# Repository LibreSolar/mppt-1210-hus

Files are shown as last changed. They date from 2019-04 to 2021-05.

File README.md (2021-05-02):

# 10A MPPT Charge Controller with USB

 Evaluation phase

User manual: [HTML](https://libre.solar/mppt-1210-hus/) / [PDF](https://libre.solar/mppt-1210-hus/manual.pdf)

Schematic: [PDF file](build/mppt-1210-hus_schematic.pdf)

Bill of Materials: [CSV file](build/mppt-1210-hus_bom.csv) or [interactive HTML BOM](https://libre.solar/mppt-1210-hus/mppt-1210-hus_ibom.html)

Firmware repository: [LibreSolar/charge-controller-firmware](https://github.com/LibreSolar/charge-controller-firmware)

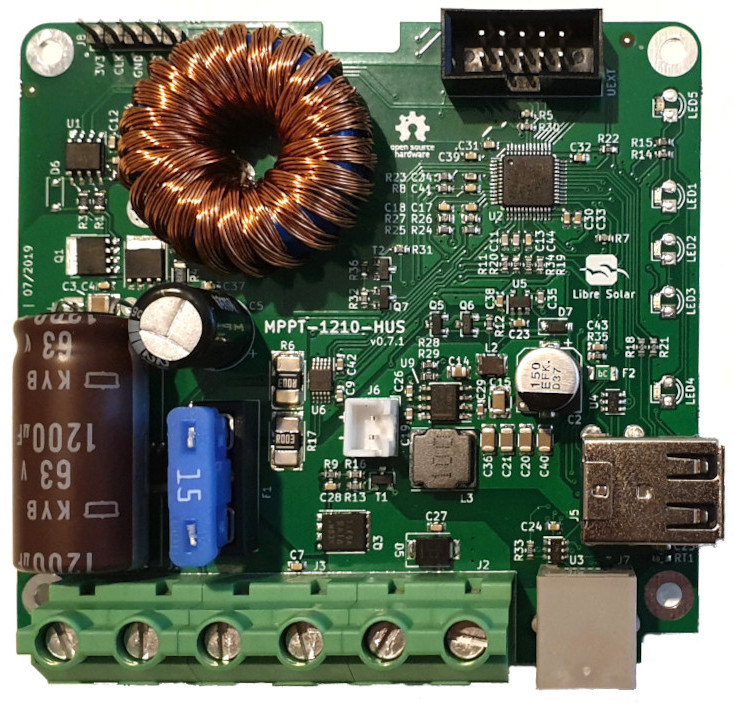
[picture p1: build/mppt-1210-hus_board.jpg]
Charge controller PCB


## Features:

- 12V battery voltage
- 40V max. solar input (36 to 48-cell panels, ideally so-called 12V panels with 36 cells)
- 10A max. charge current
- 10A max. load output current
- Low-power 32bit ARM MCU (STM32L072)
- Expandable via Olimex Universal Extension Connector (UEXT) featuring
   I2C, Serial and SPI interface (e.g. used for display, WIFI communication, etc.)
- USB charging
- High-side load switching

## Built-in protection:

- Overvoltage
- Undervoltage
- Overcurrent
- PV short circuit
- PV reverse polarity
- Battery reverse polarity (destructive, fuse is blown)

## Manual

The manual is auto-generated from the markdown files in the `manual` subfolder. See [here](https://github.com/LibreSolar/md-manual-template) for further information regarding the automated deployment.

You can contribute to the manual by cloning the repository to your private GitHub workspace and sending pull-requests with upates you made.

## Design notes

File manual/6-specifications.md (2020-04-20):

# Specifications

--------------------------------------------------------------------------------------------
Feature                         Value                   Comment
------------------------------  ----------------------- ------------------------------------
**Battery**

Nominal system voltage          12 V

Maximum voltage                 16 V

Maximum charge current          10 A

Quiescent current               < 10 mA

**PV module input**

Maximum open circuit voltage    40 V                    low temperature to be considered

Number of cells per module      36 to 48

Maximum short circuit current   10 A

Maximum nominal power           150 W

Conversion efficiency           >98% max.

**Load output**

Maximum current                 10 A

Switch type                     high-side

**USB charging port**

Maximum current                 2.0 A                   total for both ports

**Standard settings**

Battery type                    Lead-acid               safe general settings, also
                                                        suitable for LFP

Charge algorithm                3-stage                 configurable

Topping / absorption voltage    14.4 V                  configurable

Trickle charging                13.8 V                  configurable

Load disconnect voltage         11.7 V                  configurable, current-compensated

Load reconnect voltage          12.3 V                  configurable

Temperature compensation        -3 mV/K/cell            configurable

**Interfaces**

UEXT                            I2C, SPI, UART          internal, can be used for
                                                        displays, etc.

LS.one                                                  for external communication

**Protection**

Overvoltage

Undervoltage

Overcurrent

PV short circuit

PV reverse polarity                                     for max. module open circuit
                                                        voltage of around 40V

Battery reverse polarity                                destructive, fuse is blown

**Environmental conditions**

Operating ambient temperature   -10 °C to +50 °C

Storage temperature             -20 °C to +60 °C

Humidity                        <95%, non-condensing

**Mechanical design**

Screw terminals                 max. 6 mm² / AWG10

Type of internal fuse           15 A                    Automotive blade fuse (ATO)

Protection class                IP 20                   with housing (3D files available)

Weight

Dimensions

**Standards**

Power and function              EN/IEC 62509,           Tested in non-certified lab only
                                EN/IEC 62093
------------------------------  ----------------------- ------------------------------------

Table: Overview of specifications

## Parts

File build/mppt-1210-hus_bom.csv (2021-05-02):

Component | References | Value | Footprint | Description | Quantity Per PCB | Manufacturer | PartNumber | Remarks | Config | DNF | Supplier
1 | C35 | 100p | C_0603_1608 | Unpolarized capacitor | 1 | Yageo | CC0603JRNPO9BN101 | NP0/C0G
2 | C6 C11 C13 | 1n | C_0603_1608 | Unpolarized capacitor | 3 | Murata | GRM1885C2A102JA01D | NP0/C0G
3 | C4 C7 C8 C17 C18 C27 C28 C37 C41 C44 | 10n | C_0603_1608 | Unpolarized capacitor | 10 | Murata | GCM188R72A103KA37D | 100V, X7R 100V (not needed), X7R
4 | C9 C10 C19 C24 C25 C26 C30 C31 C32 C39 C42 C43 | 100n | C_0603_1608 | Unpolarized capacitor | 12 | Yageo | CC0603KRX7R9BB104
5 | C29 | 220n | C_0603_1608 | Unpolarized capacitor | 1 | Murata | GCM188R71E224KA55D | 25V, X7R
6 | C14 | 1u | C_0805_2012 | Unpolarized capacitor | 1 | Yageo | CC0805KKX7R9BB105
7 | C12 C23 C33 C34 C38 | 2.2u | C_0603_1608 | Unpolarized capacitor | 5 | Murata | GRM188R61E225KA12D | 25V, X5R
8 | C3 | 4.7u | C_1210_3225 | Unpolarized capacitor | 1 | Murata | GRJ32DC72A475KE11L | 100V, X7S
9 | C15 | 10u | C_1210_3225 | Unpolarized capacitor | 1 | Samsung | CL31A106KAHNNNE | 25V, X7R
10 | C20 C21 C36 C40 | 22u | C_1206_3216 | Unpolarized capacitor | 4 | Samsung | CL31B226MPHNNNE | 10V
11 | C2 | 150u | CP_Elec_8x6.2 | Polarised capacitor | 1 | Panasonic | EEEFK1E151P | 25V
12 | C5 | 820u | CP_Radial_D10.0mm_P5.00mm | Polarised capacitor | 1 | Panasonic | EEU-FR1E821 | 25V, 2.18A, 10x20 mm
13 | C1 | 1200u | CP_Radial_L31.5mm_D16.0mm_P7.50mm_horizontal | Polarised capacitor | 1 | United Chemi-Con | EKYB630ELL122MLN3S | 63V, 3.0A, 16x31.5
14 | D1 D4 D7 | 1N4148 | D_SOD-123 | Diode | 3 | Diodes Inc. | 1N4148W-7-F
15 | D5 | SMBJ24A | D_SMB | Diode zener | 1 | Bourns | SMBJ24A
16 | F1 | 25A | KEYSTONE-FUSE-3557-2 | Fuse | 1 | Keystone | 3557-2
17 | F2 | 50mA | R_1206_3216 |  | 1 | Bel | 0ZCJ0005FF2E
18 | J7 | 6P6C | RJ25_6P6C_TabUp | RJ connector, 6P6C (6 positions 6 connected), RJ12/RJ18/RJ25 | 1 | Wurth Electronics | 615006138421 | Alternative: Pulse E5566-Q0LK22-L
19 | J1 J2 J3 | MKDS_5-2_952 | Phoenix_Contact_MKDS_5-2-952 |  | 3 | Phoenix Contact | 1714971
20 | J6 | PWR_12V | JST_XH_B02B-XH-A_1x02_P2.50mm_Vertical | Generic connector, single row, 01x02, script generated (kicad-library-utils/schlib/autogen/connector/) | 1 | JST | B2B-XH-A (LF)(SN)
21 | J8 | ST_Nucleo_SWD | PinHeader_1x05_P2.54mm_Vertical |  | 1 | Harwin | M20-9990546 | Alternative: Standard 2.54 mm pitch header 1x5
22 | J4 | UEXT | Box_Header_2x05x2.54mm_Straight |  | 1 | On Shore Technology Inc. | 302-S101
23 | J5 | USB_A_stacked | USB_A_Wuerth_61400826021_Horizontal_Stacked | USB Type A connector (stacked) | 1 | CUI | UJ2-ADH-1-TH | Alternative: Wuerth 61400826021
24 | L2 | 2.2uH | L_1210_3225Metric | Inductor | 1 | Tayo Yuden | BRL3225T2R2M
25 | L3 | 10uH | Bourns_SRN8040TA | Inductor | 1 | Tayo Yuden | NR8040T100M | Alternative: Bourns SRN8040TA-100M
26 | L1 | 47uH | L-FERYSTER-DTMSS-27_47uH | Inductor | 1 | Feryster | DTMSS-27/0,047/15-HX |  |  |  | Feryster
27 | LED4 LED5 | green | LED_0603_D3.0mm |  | 2 | Lite-On | LTST-C190KGKT | Alternative: LTL-4231 (3mm THT)
28 | LED1 LED2 LED3 | yellow | LED_0603_D3.0mm |  | 3 | Lite-On | LTST-C191KSKT | Alternative: LTL-1CHY (3mm THT)
29 | Q3 | BSC084P03NS3 | 5X6_MOSFET | Transistor P-MOSFET (general) | 1 | Infineon | BSC084P03NS3GATMA1 | Alternative: SI7149ADP-T1-GE3
30 | Q5 Q6 Q7 | BSS83P | SOT-23 | P-MOSFET transistor, gate/source/drain | 3 | Infineon | BSS83P H6327
31 | Q1 Q2 Q4 | PSMN5R2-60YLX | 5X6_MOSFET | Transistor N-MOSFET (general) | 3 | Nexperia | PSMN5R2-60YLX | Alternative: BUK9Y6R0-60E
32 | R6 R17 | 3m | R_Bourns_CRE2512 | Resistor | 2 | Bourns | CRE2512-FZ-R003E-3
33 | R4 | 2.2 | R_1206_3216 | Resistor | 1 | Yageo | RC1206FR-072R2L
34 | R1 R3 R10 | 4.7 | R_0805_2012 | Resistor | 3 | Yageo | RC0805FR-074R7L
35 | R8 | 100 | R_0603_1608 | Resistor | 1 | Yageo | RC0603FR-07100RL
36 | R11 R14 R15 R18 R20 R21 | 470 | R_0603_1608 | Resistor | 6 | Yageo | RC0603FR-07470RL
37 | R5 R7 R13 R30 R33 R34 | 2.2k | R_0603_1608 | Resistor | 6 | Yageo | RC0603FR-072K2L
38 | R26 R27 | 5.6k | R_0603_1608 | Resistor | 2 | Yageo | RC0603FR-075K6L
39 | R9 R16 R19 R31 | 10k | R_0603_1608 | Resistor | 4 | Yageo | RC0603FR-0710KL
40 | R29 R32 | 24.9k | R_0603_1608 | Resistor | 2 | Yageo | RC0603FR-0724K9L
41 | R12 R22 R23 R24 R25 R28 R35 R36 | 100k | R_0603_1608 | Resistor | 8 | Yageo | RC0603FR-07100KL
42 | R2 | 1M | R_0603_1608 | Resistor | 1 | Yageo | RC0603FR-071ML
43 | RT1 | 10k NTC | R_0603_1608 | Thermistor with Negative Temperature Coefficient (NTC) | 1 | Murata | NCU18XH103E6SRB
44 | T1 T2 | MMBT3904 | SOT-23 | 0.8A Ic, 45V Vce, NPN Transistor, SOT-23 | 2 | Diodes Inc. | MMBT3904-7-F
45 | U5 | AP2210-3.3 | SOT-23-5 | 300mA low dropout linear regulator, shutdown pin, 1.5V fixed positive output, SOT-23-5 package | 1 | Diodes Inc. | AP2210K-3.3TRG1 | Alternative: MIC5225
46 | U3 U4 | D1213A-04SO | SOT-23-6 | Transient voltage suppressor designed to protect high speed data lines from ESD, EFT, and lightning | 2 | Diodes Inc. | D1213A-04SO | Alternative: IP4220CZ6
47 | U6 | INA2181 | VSSOP-10_3.0x3.0mm_P0.5mm |  | 1 | Texas Instruments | INA2181A2IDGS | Gain 50
48 | U1 | LM5109BMA | SOIC-8_3.9x4.9mm_Pitch1.27mm |  | 1 | Texas Instruments | LM5109BMAX/NOPB
49 | U9 | LMR33630 | TI_SO-PowerPAD-8_ThermalVias | SIMPLE SWITCHER® 3.8V to 36V, 3A Synchronous Buck Converter With Ultra-Low EMI | 1 | Texas Instruments | LMR33630ADDA | 400 kHz version
50 | U2 | STM32L072CZT6 | LQFP-48_7x7mm_P0.5mm | ARM Cortex-M0+ MCU, 192KB flash, 20KB RAM, 32MHz, 1.65-3.6V, 37 GPIO, LQFP-48 | 1 | ST Microelectronics | STM32L072CZT6 | Alternative: STM32L073CZT6

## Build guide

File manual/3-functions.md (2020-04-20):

# Description of Functions

The following chapter describes the primary functions of the charge controller. With expert knowledge, the firmware can be adjusted to suit your own needs and implement new features, including different control algorithms, wireless communication interfaces, displays, etc.

## MPPT

This charge controller is a so-called maximum power point tracker (MPPT), which automatically adapts its input voltage to the connected solar panel to extracts as much power as possible.

The MPPT function can only be achieved using a DC/DC converter, which is the core part of the charge controller PCB. It can be recognized by the large inductor and the large electrolytic input and output filter capacitors.

## Three-stage battery charging

The advanced 3-stage battery charging increases life of lead-acid batteries. The setpoints for the different stages are fully configurable via the serial interface and can be adjusted to your system setup.

- **Bulk stage**

  The battery is charged with maximum possible current until the topping stage voltage limit is reached. This is the stage where the MPPT algorithm is active.

- **Topping stage**

  The batteries are charged for some time using the maximum charge voltage. After a current cutoff limit or a time limit is reached, the charger goes into trickle mode for lead-acid batteries or into standby mode for Li-ion batteries.

  This stage is also called **absorption** mode. In case of Li-ion batteries, this is the constant voltage (CV) charging phase.

- **Trickle stage**

  This stage is kept forever for a lead-acid battery and keeps the battery at full state of charge. If too much power is drawn from the battery, the charger automatically goes back to bulk charging stage.

## Load output

In order to protect the battery from deep-discharge, consumers connected to the load ouput are automatically disconnected at low state of charge. As soon as the voltage rises again, the load port is switched back on.

## USB output

The USB port provides power supply for mobile devices like phones. The maximum current per port is 1.5 A, with 2.0 A maximum for both ports.

## Communication interface

This charge controller is equipped with a LS.one port, which incorportates an UART serial interface. It uses the [ThingSet communication protocol](https://libre.solar/thingset/) and allows configuration, monitoring and control of the charge controller.

## Temperature compensation

The battery voltage setpoints for the different charging stages have to be adjusted depending on the battery temperature. The temperature can either be estimated based on temperatures measured inside the charge controller or it can be directly measured at the battery using the external temperature sensor to maximize performance. The external temperature sensor is also connected via the LS.one port.

## LED indicator

The bottom LED close to the USB port indicates if the load output and USB port are enabled. If the light goes off, it means the battery was low and the charge controller protected it from deep-discharging.

The three middle LEDs indicate the state of charge (SOC) of the connected battery. More LEDs means more energy is present in the battery.

The top LED can be freely configured by the firmware developer, e.g. to indicate data transmission.

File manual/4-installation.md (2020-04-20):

# Installation

The following image describes the different terminals and interfaces of the charge controller PCB.

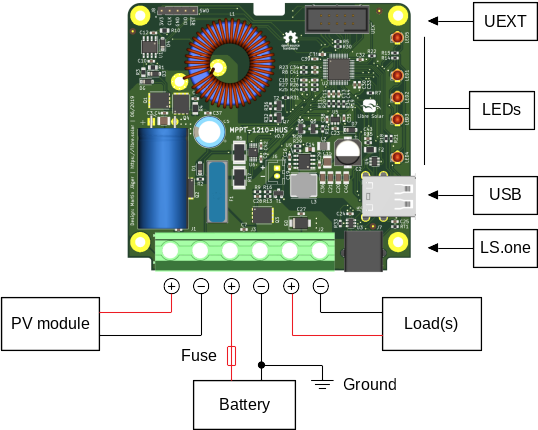
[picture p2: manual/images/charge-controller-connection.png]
Charge controller connection diagram


The charge controller features a high-side load switch and should be grounded at the negative battery terminal. There should be no additional grounding of the system. Most important, the wires to the solar panel should not be connected anywhere else except for the charge controller PV input.

## Connection order

1. Connect the battery to the battery port. As the fuse inside the charge controller cannot protect the wire between battery and charge controller, an additional fuse should be installed close to the poitive battery terminal. Small sparks during connection of the battery are normal and acceptable.

2. Cover the solar panel and afterwards connect the wires to the PV input terminal.

3. As a last step, connect the loads like lights, etc. to the load output.

The charge controller is now ready to use.

Disconnection should be done in opposite order.

## Compatible batteries

This charge controller can charge any battery with a nominal voltage of 12 V.

The default settings are safe for all lead-acid batteries, but should be adjusted according to the information provided in the battery datasheet.

For Li-ion batteries you need to configure the voltage setpoints manually using the LS.one serial interface. You must also deactivate the float charging stage.

## Solar modules

The MPPT algorithm can automatically adapt to different types of modules. Any module with 36 to 48 cells in series is suitable. The maximum open circuit voltage even under cold ambient temperature conditions must be below 40 V. Even though the controller automatically derates its power in case of overload, the nominal power under standard test conditions (STC) of the module should not exceed 150 W.

Solar modules need direct sunlight to work properly. Indirect light and partial shading will reduce the performance. Make sure to face the module towards the sun.

Read the datasheet of your solar module for more information about the specifications.

## Mounting

Fix the device vertical at non-flammable surface with the power terminals facing downwards.

The charge controller should be mounted as close to the battery as possible, but avoiding any contact with battery acid or gas emissions.

Never mount the device in a fuel storage compartment, as the fuse can create sparks.

## Wiring and Grounding

The minimum wire cross-section should be 2.5 mm². It is recommended to use 6 mm² wires, which is the maximum the terminals can handle.

The length between charge controller and battery should be less than 1 m.

Use suitable fuses in the wiring harness connected to the load terminal if the cross-section is decreased.

If necessary, only ground the energy system at a single point, which should be at the negative battery terminal.

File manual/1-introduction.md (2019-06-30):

# Introduction

Thanks for using this Libre Solar charge controller.

The manual describes the usage and most important functions of this specific device. Please visit the [Libre Solar website](https://libre.solar) for general information about charge controllers and other devices for DC energy systems.

Read this manual carefully and make sure you understand everything before starting with installation of the charge controller.

Same as the hardware and firmware of the charge controller, also this manual is open source. If you find any error or have suggestions for improvement, please contribute to [the repository on GitHub](https://github.com/LibreSolar/MPPT-1210-HUS).

## Disclaimer

Due to the fact we are not providing a product in the legal sense, we are also not providing any warranty in any aspect.

The user manual described here has been written and checked with care and to the best of our knowledge.

Libre Solar assumes no liability for the accuracy, completeness or quality of the information provided. Liability claims against the team for material, physical or immaterial damages caused by the use or non-use of the information provided or by the use of incorrect and/or incomplete information are excluded.

All information and instructions are non-binding. Libre Solar reserves the right to change, supplement or delete parts of the pages or the entire document without prior notice.

<div style="text-align:center">
CC-BY-SA
</div>

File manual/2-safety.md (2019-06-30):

# Safety Instructions

The charge controller shall be used only for the intended application.

- The maximum voltage and power of the connected solar panel must not exceed the limits of the charge controller. Make sure to consider also the increased voltage of solar panels at low ambient temperatures.

- Ensure that the charge controller is configured correctly for the used battery type.

- Use lithium ion batteries (e.g. LiFePO4) only if they contain an integrated battery management system (BMS) for additional protection.

Install the device considering general best practices for electrical and mechanical installations in accordance to laws in your country.

- An additional fuse must be installed as close to the battery positive terminal as possible.

- As sparks can occur during connection of the battery or solar panel wires, don't install the charge controller close to any flammable materials.

- The wire cross-section has to be large enough to handle at least the maximum specified current of the charge controller.

- Use insulated tools only.

- Fix the wires outside the charge controller to provide a strain relief.

- Mount the device vertically on a solid, non-inflammable wall only, with the battery terminals facing downwards.

- Keep free space for ventilation next to the device and don't cover the housing.

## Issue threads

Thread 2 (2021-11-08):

LS_DRV and Q2 interaction

X-Ryl669, 2021-11-08:
I'm wondering why Q2 gate is connected to LS_DRV signal. I'd have understood if it was connected to a STM32 GPIO as a way to prevent current flowing in reverse from the battery to the solar panel.

In the current schematic, in normal operating conditions, wouldn't Q2 enable/disable with LS_DRV, thus preventing some current to flow from the solar panel when "charging" the inductor and, as such, reducing the efficiency of the DC/DC buck stage ?

martinjaeger, 2021-11-08:
The trick is that the gate of Q2 (with its parasitic capacitance) is discharged through the weak 1MOhm pull-down only and discharging takes longer than one switching period. This means while the half bridge driver is switching, the gate of Q2 is continuously topped up and thus stays on all the time. The diode D1 is necessary to prevent it from being discharged by the MOSFET driver together with Q4.

martinjaeger, 2021-11-08:
The duty cycle will never get to 100% as we need to supply the bootstrapping capacitor C10 to have sufficient driving voltage for the high-side MOSFET. So Q4 will also never be turned off completely.

This is a synchronous buck topology, so at very low average currents the inductor current waveform can even get below zero for short periods of time.

X-Ryl669, 2021-11-08:
The main issue is when Q4 is turned **on** completely (or close to completely). In that case, it can burn, since the battery will shortcut into it directly. And this happens when the duty cycle is close to 0, IIUC.

In many of not most synchronous buck topology I know about, this is avoided by turning both Q1 and Q4 off at the same time when the duty cycle is 0-ish (threshold to be defined). Then, if Q1 and Q4 are off, Q2 will be off too and I don't see how it can bootstrap to on again later on, since you need to turn Q4 on to be able to read *a meaningful* solar panel voltage (that is, between solar + and solar - minus voltage drop in Rds of Q2).

martinjaeger, 2021-11-08:
The duty cycle is defined as follows:
```
D = t_HS,on / (t_HS,on + t_HS,off) = V_out / V_in
```
I can never go towards 0 (prevented by firmware), as this would mean that the input voltage goes towards infinity (given a fixed battery output voltage).

See also [DC/DC converter on learn.libre.solar](https://learn.libre.solar/development/dcdc_converter.html).

X-Ryl669, 2021-11-08:
Right. This is the theoretical ratio, but the real ratio is less obvious.

Since Q4 will need at least 5V for the PSMN5R2 to commute, there's a minimum duty cycle where it'll not actually commute in saturation mode and instead, work more or less in linear mode. When this happens, the inductor current will flow in the MOSFET and so will the battery current, with a DC Vout voltage (and not the *lower* saturated Vds gate voltage).

Depending on the "on" time, so the actual duty cycle for this transistor (let's say 1%), it means that you'll have a huge power consumption on the drain/source of the MOSFET with 12V on its Rds. That's the main reason why those transistors are frequently blown up on the synchronous buck designs.

With typical numbers, if you have Vin at 80V and Vout at 12V (nominal), it means that a duty cycle of less than 15% will actually turn Q4 always on and in that case, you'll have 12V on a equivalent resistance of Rds + 3mOhm + inductor parasitic resistance (let's say 1 ohm total), so a power to dissipate of 144W*15% ~= 22W in the MOSFET.

To avoid this, when the duty cycle is below some threshold computed from the MOSFET maximum allowed power dissipation with a margin (and the actual measured Vout value), the main idea is to switch off both MOSFET (Q4 and Q1 in that case), which isolate Vin from Vout instead. If you don't do this, I wonder you'll have a lot of Q4 to replace in real life usage of the circuit.

Else if you do this, Q2 will, later, isolate solar - from the ground and that's my issue in understanding your circuit.

martinjaeger, 2021-11-08:
I'm not sure if I understand correctly what you mean, but it's an interesting discussion!

So let's assume that the battery voltage is always above 10V, otherwise we don't start the DC/DC. In this case our MOSFET driver supply voltage is slightly less than the 10V, but still enough to turn the PSMN5R2 (logic-level MOSFET) fully on. The MOSFET will be in the linear region only for a couple of nanoseconds per switching cycle during turn-on and turn-off, but not 15% of the time. And the switching losses will be the same independent of the duty cycle.

Turning both MOSFETs Q4 and Q1 off at the same time means we turn off the entire DC/DC converter. So why would we want to do that while there is still solar power available?

X-Ryl669, 2021-11-08:
I'm reading the code right now and it's well written so it's easy to follow.
If I understand correctly, you set the minimum duty cycle from this line:
```
    half_bridge_init(DT_PROP(DT_INST(0, half_bridge), frequency) / 1000,
        DT_PROP(DT_INST(0, half_bridge), deadtime), 12 / hs_voltage_max, 0.97);
```
So the minimum value is a dynamic property (good!)

However, I don't see when you are disabling the timer for the PWM signal generation, so it would mean that you'd set a duty cycle to the minimum value and that's it.

martinjaeger, 2021-11-08:
> However, I don't see when you are disabling the timer for the PWM signal generation, so it would mean that you'd set a duty cycle to the minimum value and that's it.

It is stopped in the `Dcdc::control()` function (can be for various reasons like low power, too high voltage, manually stopped).

X-Ryl669, 2021-11-08:
Right (sorry, posting answer in FIFO order). I'm not saying that Q4 is in the linear region 15% of the time. It's in the saturation region ~85% of the time if the duty cycle is 15% (well, except for the negligible time where both Q1 and Q4 are off to avoid half bridge shortcut). The mosfet driver circuit takes 15ns of rise time (from TI's datasheet), so I'd say that the linear region is small, 30ns per cycle, yet I don't know the PWM frequency to compute the actual linear region ratio.
I assume it's peanuts.

In the example above however, you have the solar panel producing 0A at 80V (typical Voc) and a battery at 12V. You want Vout = 12V so technically, switching off the DC/DC is the best move to do, efficiency wise. If you don't, the duty cycle will turn on Q4 85% of the time (Duty = 0.15), and when it's doing that, the battery current will flow in Q4,  heating it up. You want 0A to flow in the battery (and obviously, you don't want the battery to act a source).

In the 15% of the time Q1 is on and Q4 is off, the solar panel is "forced in production", and a current will flow from the solar panel to the inductor & capacitor. Slowly lowering the panel voltage and increasing the current from the panel, increasing the duty cycle, yet, this will actually take a lot of time and while the MPPT is converging, you'll still heat the Q4 mosfet like crazy, until it burns or you finally reach a duty cycle where it's safe.

X-Ryl669, 2021-11-08:
This example above is what happens when the battery is charged and you want 0A to go into the battery. In that case, still running the PWM seems like a dangerous action IMHO.
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
X-Ryl669, 2021-11-09:
BTW, I've used circuitlab to simulate, but I'm running of the trial limited time. Feel free to copy the circuit on your simulator to see by yourself. Ideally, you can simulate the whole circuit better with microcap software since it account for heat simulation and burning components

martinjaeger, 2021-11-09:
> Nope, it only provide a path for the current if the solar panel is sinking them, but solar panels have a diode preventing current to flow backward. So when you Q1 is on, the current can't flow in the solar panel. It would even add to the issue since the solar panel current will flow to charge the inductor.

But we have bulk electrolytic capacitors at the input of the DC/DC converter which will receive the current, so the energy is essentially continuously swapped between input and output capacitor at 0A average current.

X-Ryl669, 2021-11-09:
And even [here](https://github.com/LibreSolar/mppt-2420-lc/issues/29)

X-Ryl669, 2021-11-09:
Electrolytic capacitor will be charged in the 80V 0A mode and there's nothing to discharge them, so no, they won't sink the current.

martinjaeger, 2021-11-09:
It's a bit funny that you insist that the circuit does not work and that it would burn low-side MOSFETs even though it is actually working since years in several different applications.

I don't know what's wrong with the designs on Instructables. I suspect it's a firmware issue (e.g. control algorithm bug) or a not well matched dead-time, which is software-configurable in the Libre Solar designs, but fixed if you use an IR2104.

martinjaeger, 2021-11-09:
> My initial remark was, if you turn off Q4 and Q1, then how Q2 is controlled. If you don't turn off Q4 & Q1 like all other people do to avoid burning the Q4 mosfet, then Q2 is controlled and all is fine.

"All other people" being those two people on Instructables?

> I think I've proved above that turning off the PWM is the best action efficiency-wise when reaching low duty cycle (instead of running the circuit with such low duty and heating the mosfet).

No. Turning the MOSFETs off as soon as the *average* current towards the battery gets negative is the best action for best efficiency. If you can't measure currents around 0A or in negative direction, this approach might be difficult, though. In that case you might have to turn off based on duty cycle thresholds.

> I think I've proved that in that situation Q4 is heating up and is more likely to burn.

No. You have simulated a circuit that is completely different from the actual circuit of this MPPT.

> But turning off the PWM would have even avoided this requirement and increased the efficiency in the longest usage time (since in most case, once you've maximized your battery charge, the circuit will run in low duty mode for as long as you don't draw load's current from the system). With a PWM off, the battery drain current is essentially 0, the voltage on the battery is constant and good, the solar current is 0. It's crazy to switch the transistors at 70kHz not to move any electron and just convert them to heat.

Maybe there was a misunderstanding. The PWM will eventually be switched off, but only as soon as no current goes into the battery anymore. As long as there is still a little bit of power coming from the solar panel, low efficiency is still better than 0% efficiency (PWM off, no power flow).

X-Ryl669, 2022-04-01:
Sorry, I missed your answer... My bad.

> The PWM will eventually be switched off, but only as soon as no current goes into the battery anymore. As long as there is still a little bit of power coming from the solar panel, low efficiency is still better than 0% efficiency (PWM off, no power flow).

Ok, that's what I asked initially. The situation I was describing was exactly this, static full charged battery. In that case, the PWM will be off and that's ok (and expected).

The threshold from where to turn off the PWM is when the "available" energy from the solar panel is just above the energy lost in the Q4/Q1/inductor tuple. Ideally, this threshold should be high enough not to run the mosfet in their "heat up / low efficiency" region to avoid premature fatigue.

 I've seen it's dynamic in the code, and I was wondering where it's set and you've answered.

How it's computed, I don't know, but I guess it's possible to measure it with an amp meter and figure out what is the best value and take some margin. Maybe you have a simulation of the whole circuit and it can be set up from here ?

Using the parasitic capacitance of Q2 (thus not in the schematic and probably variable between each board/chip) was what I failed to see. Maybe it would be better to have a very small (pF) capacitor on the schematic ?

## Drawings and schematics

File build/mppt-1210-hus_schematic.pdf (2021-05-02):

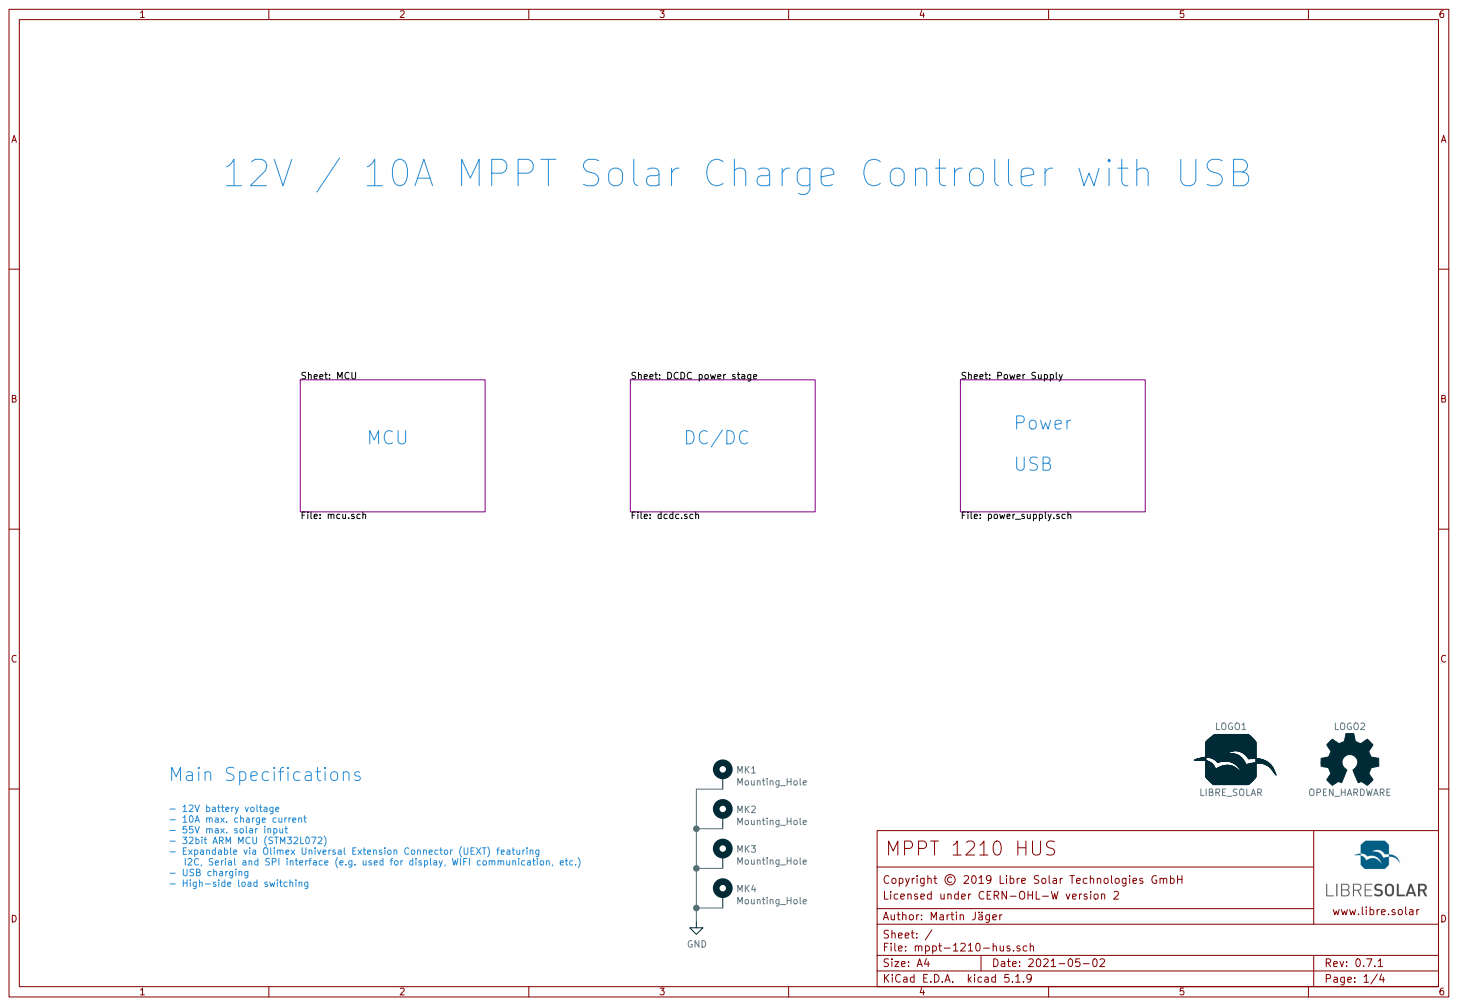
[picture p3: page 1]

12V / 10A MPPT Solar Charge Controller with USB

- 12V battery voltage
- 10A max. charge current
- 55V max. solar input
- 32bit ARM MCU (STM32L072)
- Expandable via Olimex Universal Extension Connector (UEXT) featuring
I2C, Serial and SPI interface (e.g. used for display, WIFI communication, etc.)
- USB charging
- High-side load switching

File: mppt-1210-hus.sch Sheet: / Copyright © 2019 Libre Solar Technologies GmbH

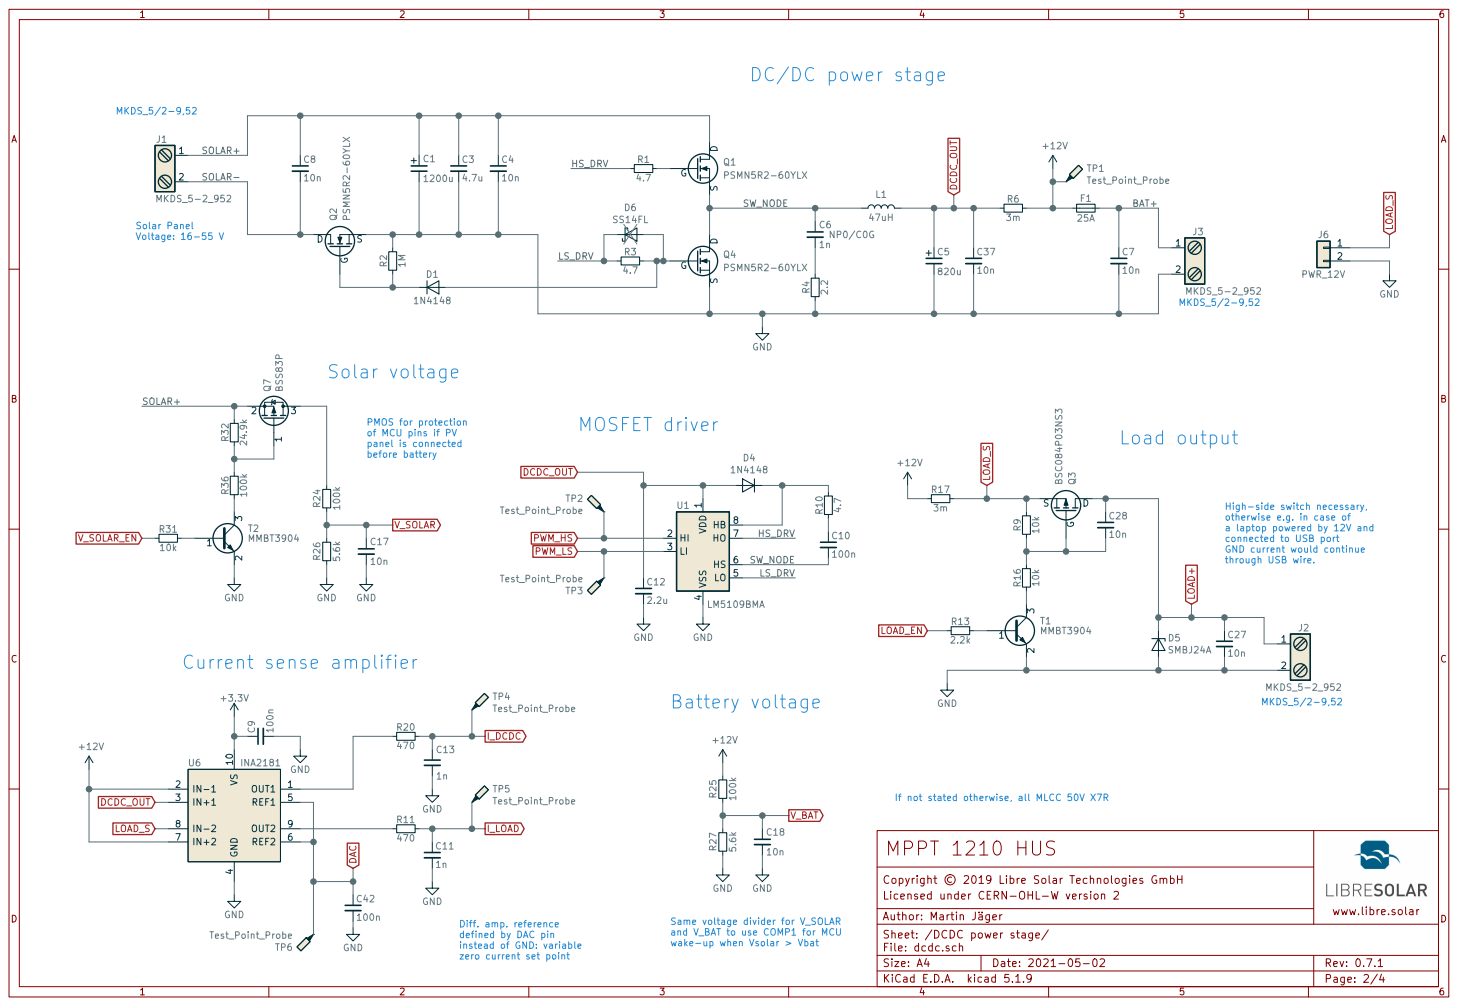
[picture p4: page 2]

DC/DC power stage

PMOS for protection
of MCU pins if PV
panel is connected
before battery
DCDC_OUT DAC

Load output MOSFET driver

High-side switch necessary,
otherwise e.g. in case of
a laptop powered by 12V and
connected to USB port GND current would continue

Copyright © 2019 Libre Solar Technologies GmbH

Same voltage divider for V_SOLAR
and V_BAT to use COMP1 for MCU
wake-up when Vsolar > Vbat

File: dcdc.sch Sheet: /DCDC power stage/

defined by DAC pin
instead of GND: variable
zero current set point

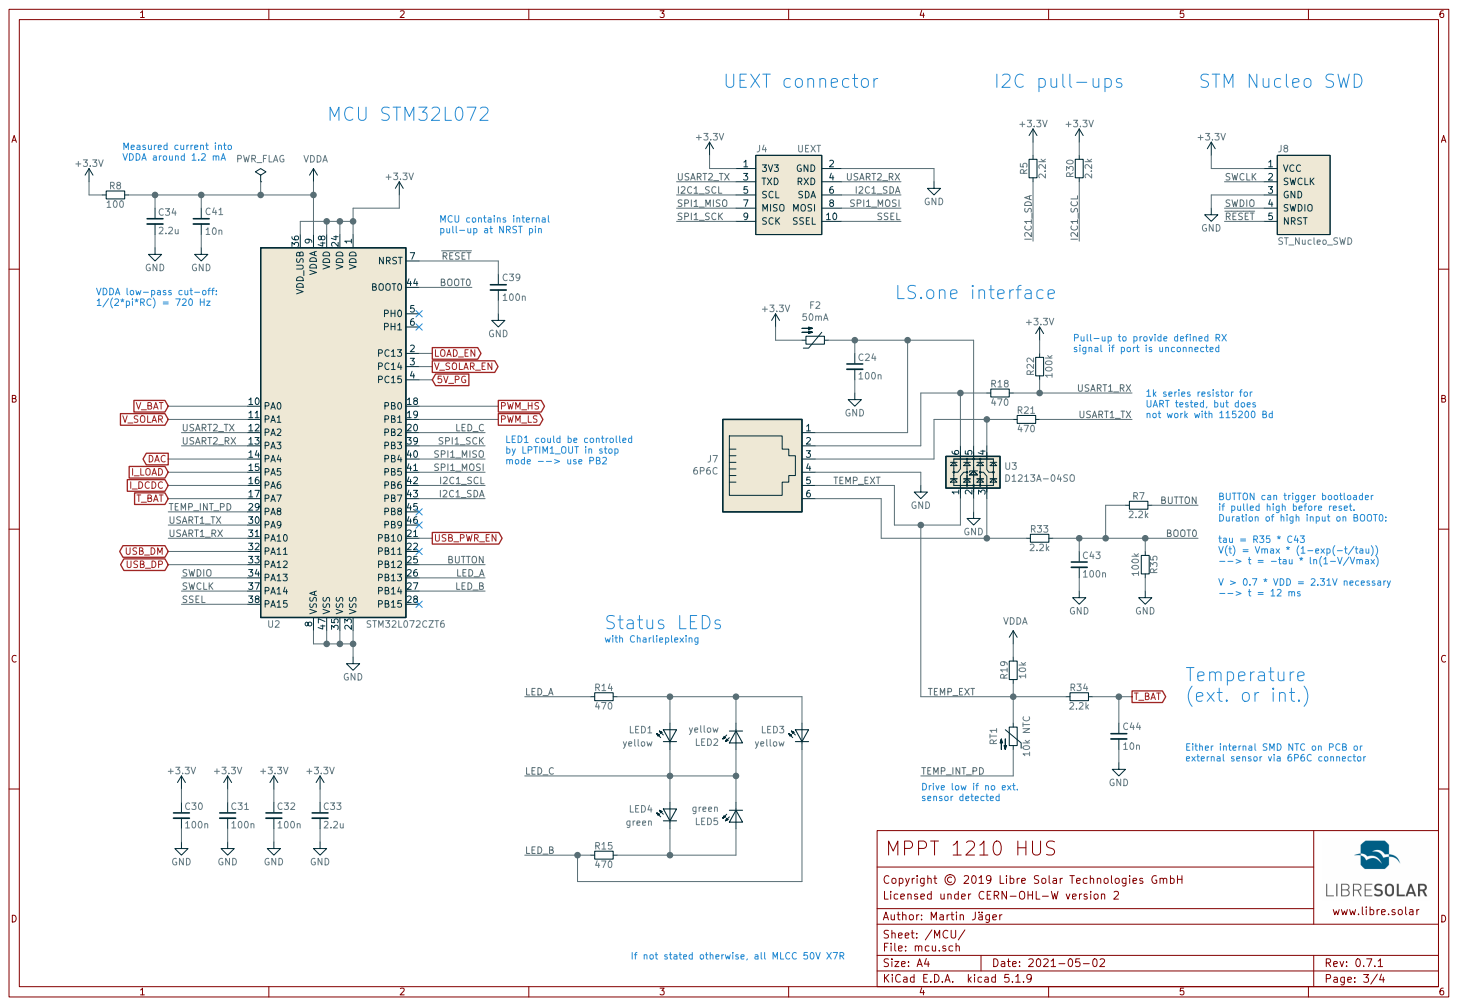
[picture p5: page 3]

Measured current into VDDA around 1.2 mA

MCU contains internal pull-up at NRST pin

9 VDD_USB 36 VSS 23 VSS 35 VSS 47 VSSA U2 8STM32L072CZT6 GND

(ext. or int.) Either internal SMD NTC on PCB or external sensor via 6P6C connector LS.one interface

VDDA low-pass cut-off:

signal if port is unconnected Drive low if no ext. sensor detected

Pull-up to provide defined RX

1k series resistor for UART tested, but does not work with 115200 Bd

if pulled high before reset.
Duration of high input on BOOT0:

tau = R35 * C43 V(t) = Vmax * (1-exp(-t/tau))

File: mcu.sch Sheet: /MCU/ Copyright © 2019 Libre Solar Technologies GmbH

If not stated otherwise, all MLCC 50V X7R

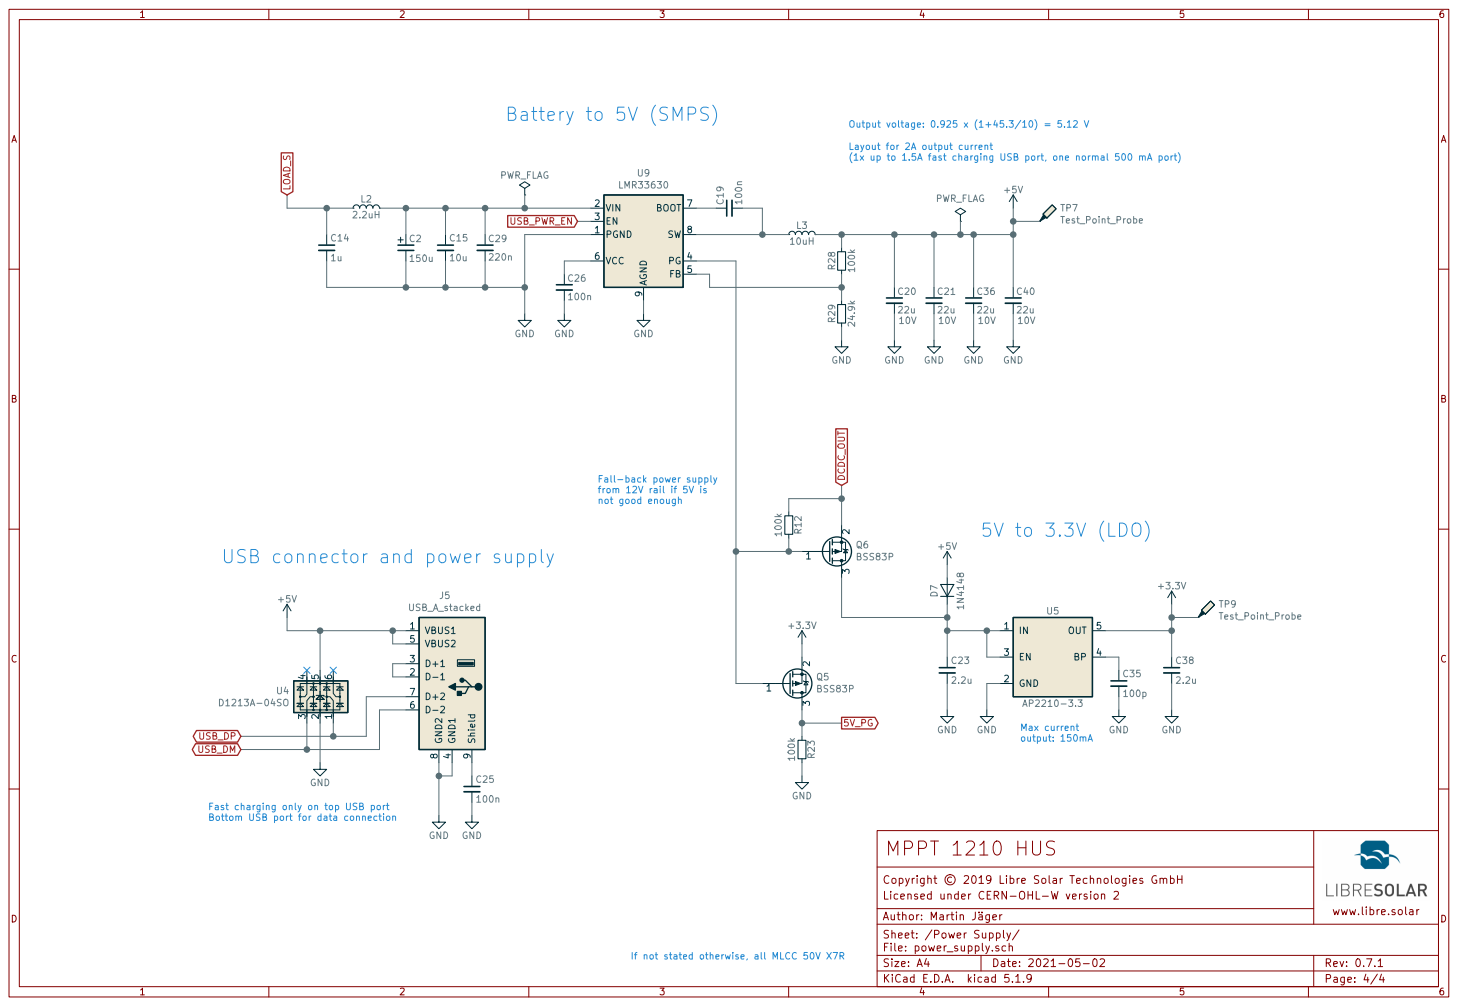
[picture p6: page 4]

Layout for 2A output current
(1x up to 1.5A fast charging USB port, one normal 500 mA port)

Fall-back power supply
from 12V rail if 5V is not good enough

5V to 3.3V (LDO) Max current output: 150mA

USB connector and power supply

Fast charging only on top USB port
Bottom USB port for data connection

Copyright © 2019 Libre Solar Technologies GmbH

If not stated otherwise, all MLCC 50V X7R

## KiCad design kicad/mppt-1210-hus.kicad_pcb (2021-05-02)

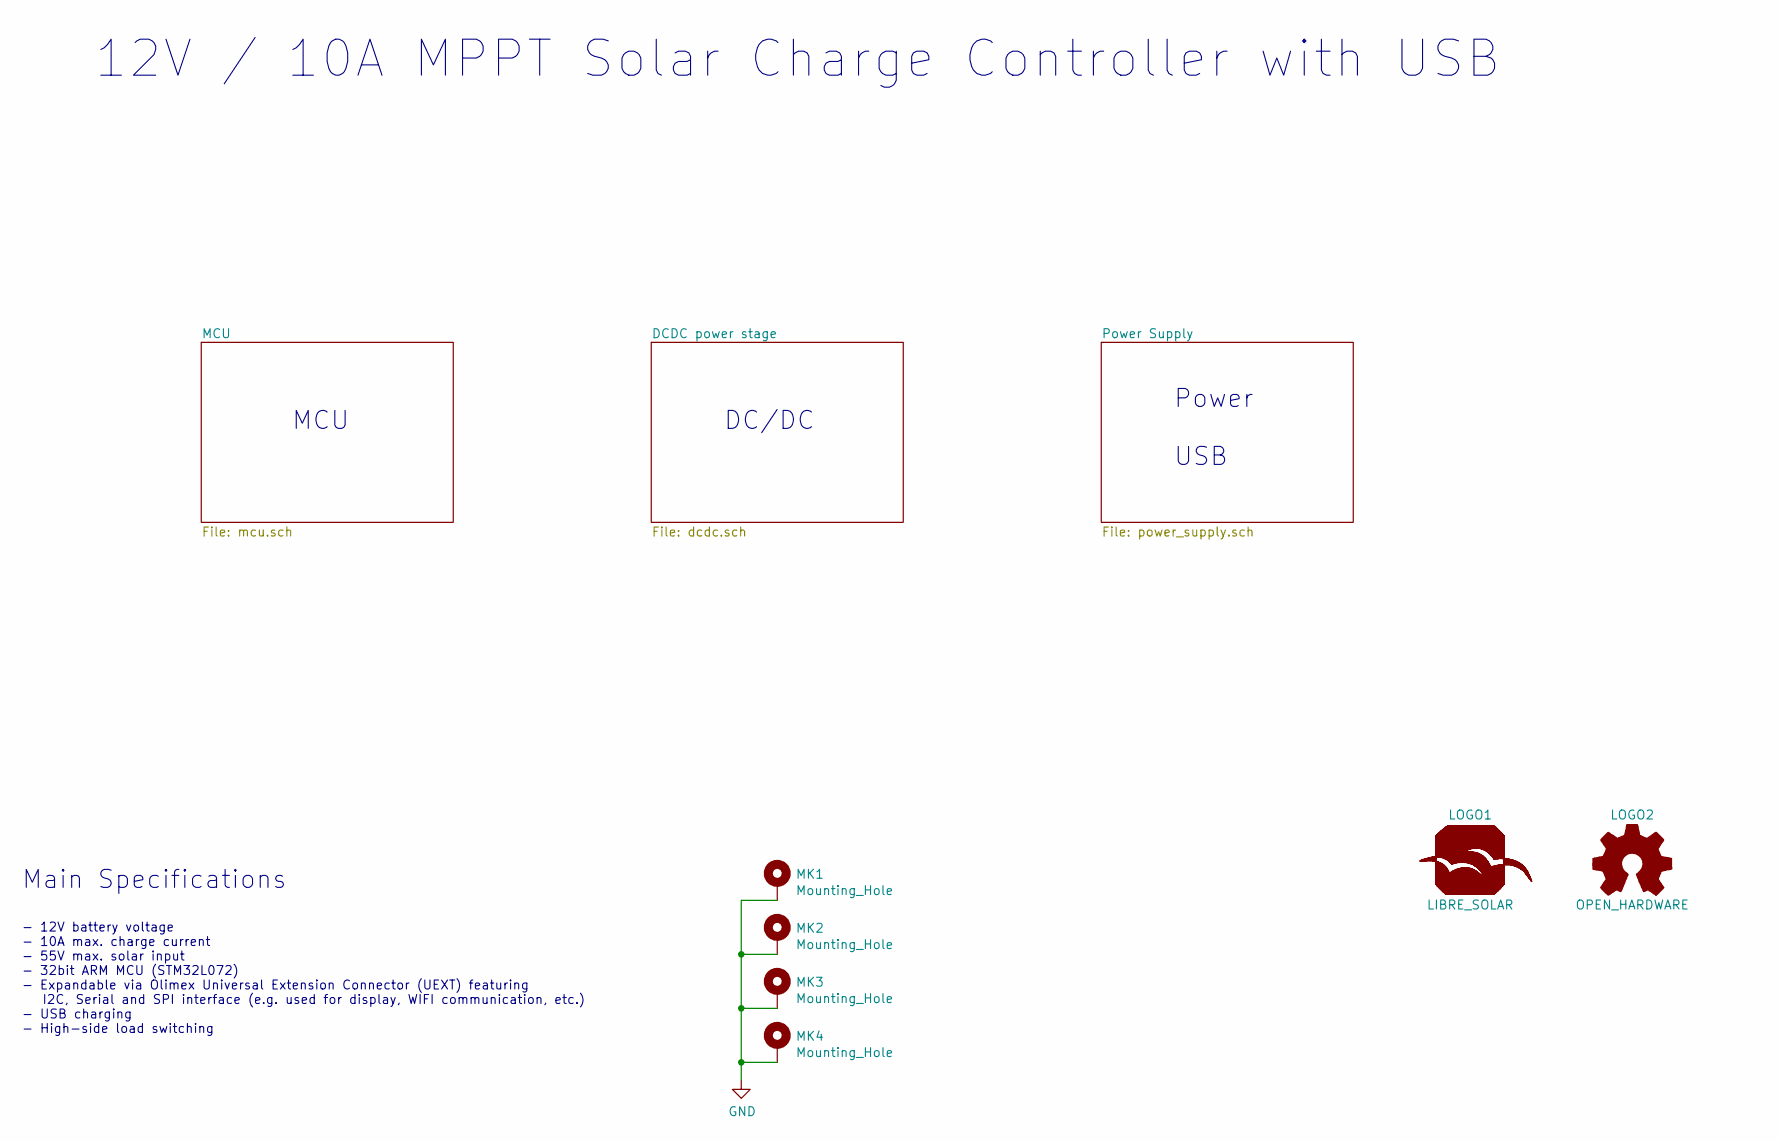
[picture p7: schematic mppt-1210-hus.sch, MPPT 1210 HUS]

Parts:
LOGO1: LIBRE_SOLAR; LIBRESOLAR_LOGO
LOGO2: OPEN_HARDWARE; OSHW-Logo_5.7x6mm_SilkScreen
MK1, MK2, MK3, MK4: Mounting_Hole; MountingHole_3.2mm_M3_Pad

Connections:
GND: MK1.1, MK2.1, MK3.1, MK4.1; also elsewhere on the board

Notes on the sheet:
12V / 10A MPPT Solar Charge Controller with USB
Main Specifications
- 12V battery voltage - 10A max. charge current - 55V max. solar input - 32bit ARM MCU (STM32L072) - Expandable via Olimex Universal Extension Connector (UEXT) featuring I2C, Serial and SPI interface (e.g. used for display, WIFI communication, etc.) - USB charging - High-side load switching
DC/DC
MCU
Power USB

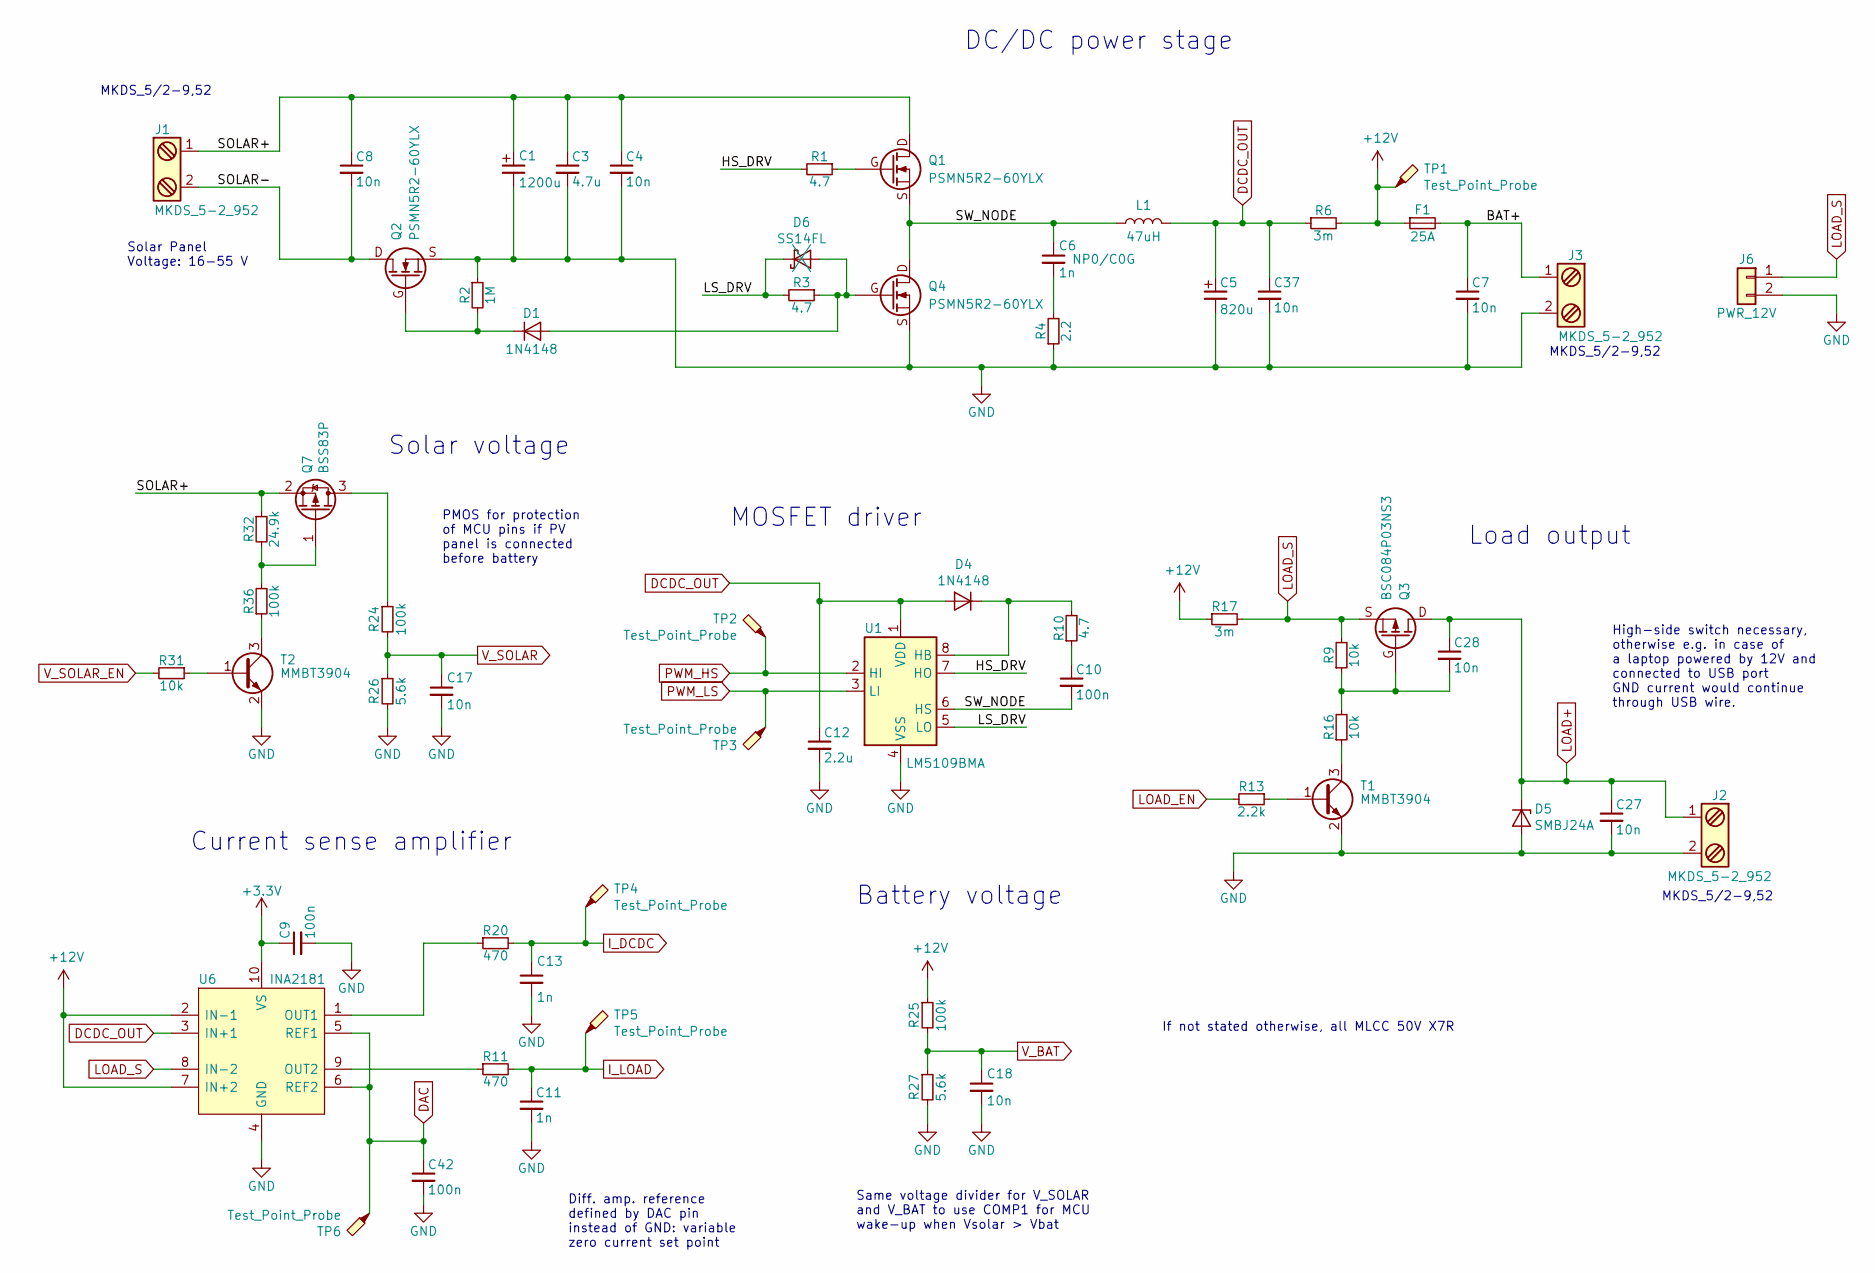
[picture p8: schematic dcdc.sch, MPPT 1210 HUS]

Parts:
C1: 1200u; CP_Radial_L31.5mm_D16.0mm_P7.50mm_horizontal; PartNumber EKYB630ELL122MLN3S
C3: 4.7u; C_1210_3225; PartNumber GRJ32DC72A475KE11L
C4, C7, C8, C17, C18, C27, C28, C37: 10n; C_0603_1608; PartNumber GCM188R72A103KA37D
C5: 820u; CP_Radial_D10.0mm_P5.00mm; PartNumber EEU-FR1E821
C6, C11, C13: 1n; C_0603_1608; PartNumber GRM1885C2A102JA01D
C9, C10, C42: 100n; C_0603_1608; PartNumber CC0603KRX7R9BB104
C12: 2.2u; C_0603_1608; PartNumber GRM188R61E225KA12D
D1, D4: 1N4148; D_SOD-123; PartNumber 1N4148W-7-F
D5: SMBJ24A; D_SMB; PartNumber SMBJ24A
D6: SS14FL; D_SOD-123; PartNumber SS14FL
F1: 25A; KEYSTONE-FUSE-3557-2; PartNumber 3557-2
J1, J2, J3: MKDS_5-2_952; Phoenix_Contact_MKDS_5-2-952; PartNumber 1714971
J6: PWR_12V; JST_XH_B02B-XH-A_1x02_P2.50mm_Vertical; PartNumber B2B-XH-A (LF)(SN)
L1: 47uH; L-FERYSTER-DTMSS-27_47uH; PartNumber DTMSS-27/0,047/15-HX
Q1, Q2, Q4: PSMN5R2-60YLX; 5X6_MOSFET; PartNumber PSMN5R2-60YLX
Q3: BSC084P03NS3; 5X6_MOSFET; PartNumber BSC084P03NS3GATMA1
Q7: BSS83P; SOT-23; PartNumber BSS83P H6327
R1, R3, R10: 4.7; R_0805_2012; PartNumber RC0805FR-074R7L
R2: 1M; R_0603_1608; PartNumber RC0603FR-071ML
R4: 2.2; R_1206_3216; PartNumber RC1206FR-072R2L
R6, R17: 3m; R_Bourns_CRE2512; PartNumber CRE2512-FZ-R003E-3
R9, R16, R31: 10k; R_0603_1608; PartNumber RC0603FR-0710KL
R11, R20: 470; R_0603_1608; PartNumber RC0603FR-07470RL
R13: 2.2k; R_0603_1608; PartNumber RC0603FR-072K2L
R24, R25, R36: 100k; R_0603_1608; PartNumber RC0603FR-07100KL
R26, R27: 5.6k; R_0603_1608; PartNumber RC0603FR-075K6L
R32: 24.9k; R_0603_1608; PartNumber RC0603FR-0724K9L
T1, T2: MMBT3904; SOT-23; PartNumber MMBT3904-7-F
TP1, TP2, TP3, TP4, TP5, TP6: Test_Point_Probe; TestPoint_Pad_D1.0mm
U1: LM5109BMA; SOIC-8_3.9x4.9mm_Pitch1.27mm; PartNumber LM5109BMAX/NOPB
U6: INA2181; VSSOP-10_3.0x3.0mm_P0.5mm; PartNumber INA2181A2IDGS

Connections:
+3V3: C9.1, U6.10 (VS); also elsewhere on the board
+12V: F1.1, R6.2, R17.1, R25.1, TP1.1, U6.2 (IN-1), U6.7 (IN+2)
/DCDC power stage/BAT+: C7.1, F1.2, J3.1
/DCDC power stage/HS_DRV: R1.2, U1.7 (HO)
/DCDC power stage/LS_DRV: D6.1 (K), R3.2, U1.5 (LO)
/DCDC power stage/SOLAR+: C1.1, C3.1, C4.1, C8.1, J1.1, Q1.D, Q7.2 (S), R32.1
/DCDC power stage/SOLAR-: C8.2, J1.2, Q2.D
/DCDC power stage/SW_NODE: C6.1, C10.2, L1.1, Q1.S, Q4.D, U1.6 (HS)
DAC: C42.1, TP6.1, U6.5 (REF1), U6.6 (REF2); also elsewhere on the board
DCDC_OUT: C5.1, C12.1, C37.1, D4.2 (A), L1.2, R6.1, U1.1 (VDD), U6.3 (IN+1); also elsewhere on the board
GND: C1.2, C3.2, C4.2, C5.2, C7.2, C9.2, C11.2, C12.2, C13.2, C17.2, C18.2, C27.2, C37.2, C42.2, D5.2 (A), J2.2, J3.2, J6.2, Q2.S, Q4.S, R2.1, R4.1, R26.2, R27.2, T1.2 (E), T2.2 (E), U1.4 (VSS), U6.4 (GND); also elsewhere on the board
I_DCDC: C13.1, R20.2, TP4.1; also elsewhere on the board
I_LOAD: C11.1, R11.2, TP5.1; also elsewhere on the board
LOAD+: C27.1, C28.1, D5.1 (K), J2.1, Q3.D
LOAD_EN: R13.2; also elsewhere on the board
LOAD_S: J6.1, Q3.S, R9.2, R17.2, U6.8 (IN-2); also elsewhere on the board
unnamed: C6.2, R4.2
unnamed: C10.1, R10.1
unnamed: C28.2, Q3.G, R9.1, R16.2
unnamed: D1.1 (K), Q2.G, R2.2
unnamed: D1.2 (A), D6.2 (A), Q4.G, R3.1
unnamed: D4.1 (K), R10.2, U1.8 (HB)
unnamed: Q1.G, R1.1
unnamed: Q7.1 (G), R32.2, R36.2
unnamed: Q7.3 (D), R24.1
unnamed: R11.1, U6.9 (OUT2)
unnamed: R13.1, T1.1 (B)
unnamed: R16.1, T1.3 (C)
unnamed: R20.1, U6.1 (OUT1)
unnamed: R31.1, T2.1 (B)
unnamed: R36.1, T2.3 (C)
PWM_HS: TP2.1, U1.2 (HI); also elsewhere on the board
PWM_LS: TP3.1, U1.3 (LI); also elsewhere on the board
V_BAT: C18.1, R25.2, R27.1; also elsewhere on the board
V_SOLAR: C17.1, R24.2, R26.1; also elsewhere on the board
V_SOLAR_EN: R31.2; also elsewhere on the board

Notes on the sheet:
Solar Panel Voltage: 16-55 V
DC/DC power stage
Load output
MOSFET driver
If not stated otherwise, all MLCC 50V X7R
MKDS_5/2-9,52
Current sense amplifier
Solar voltage
Diff. amp. reference defined by DAC pin instead of GND: variable zero current set point
Same voltage divider for V_SOLAR and V_BAT to use COMP1 for MCU wake-up when Vsolar > Vbat
High-side switch necessary, otherwise e.g. in case of a laptop powered by 12V and connected to USB port GND current would continue through USB wire.
Battery voltage
PMOS for protection of MCU pins if PV panel is connected before battery

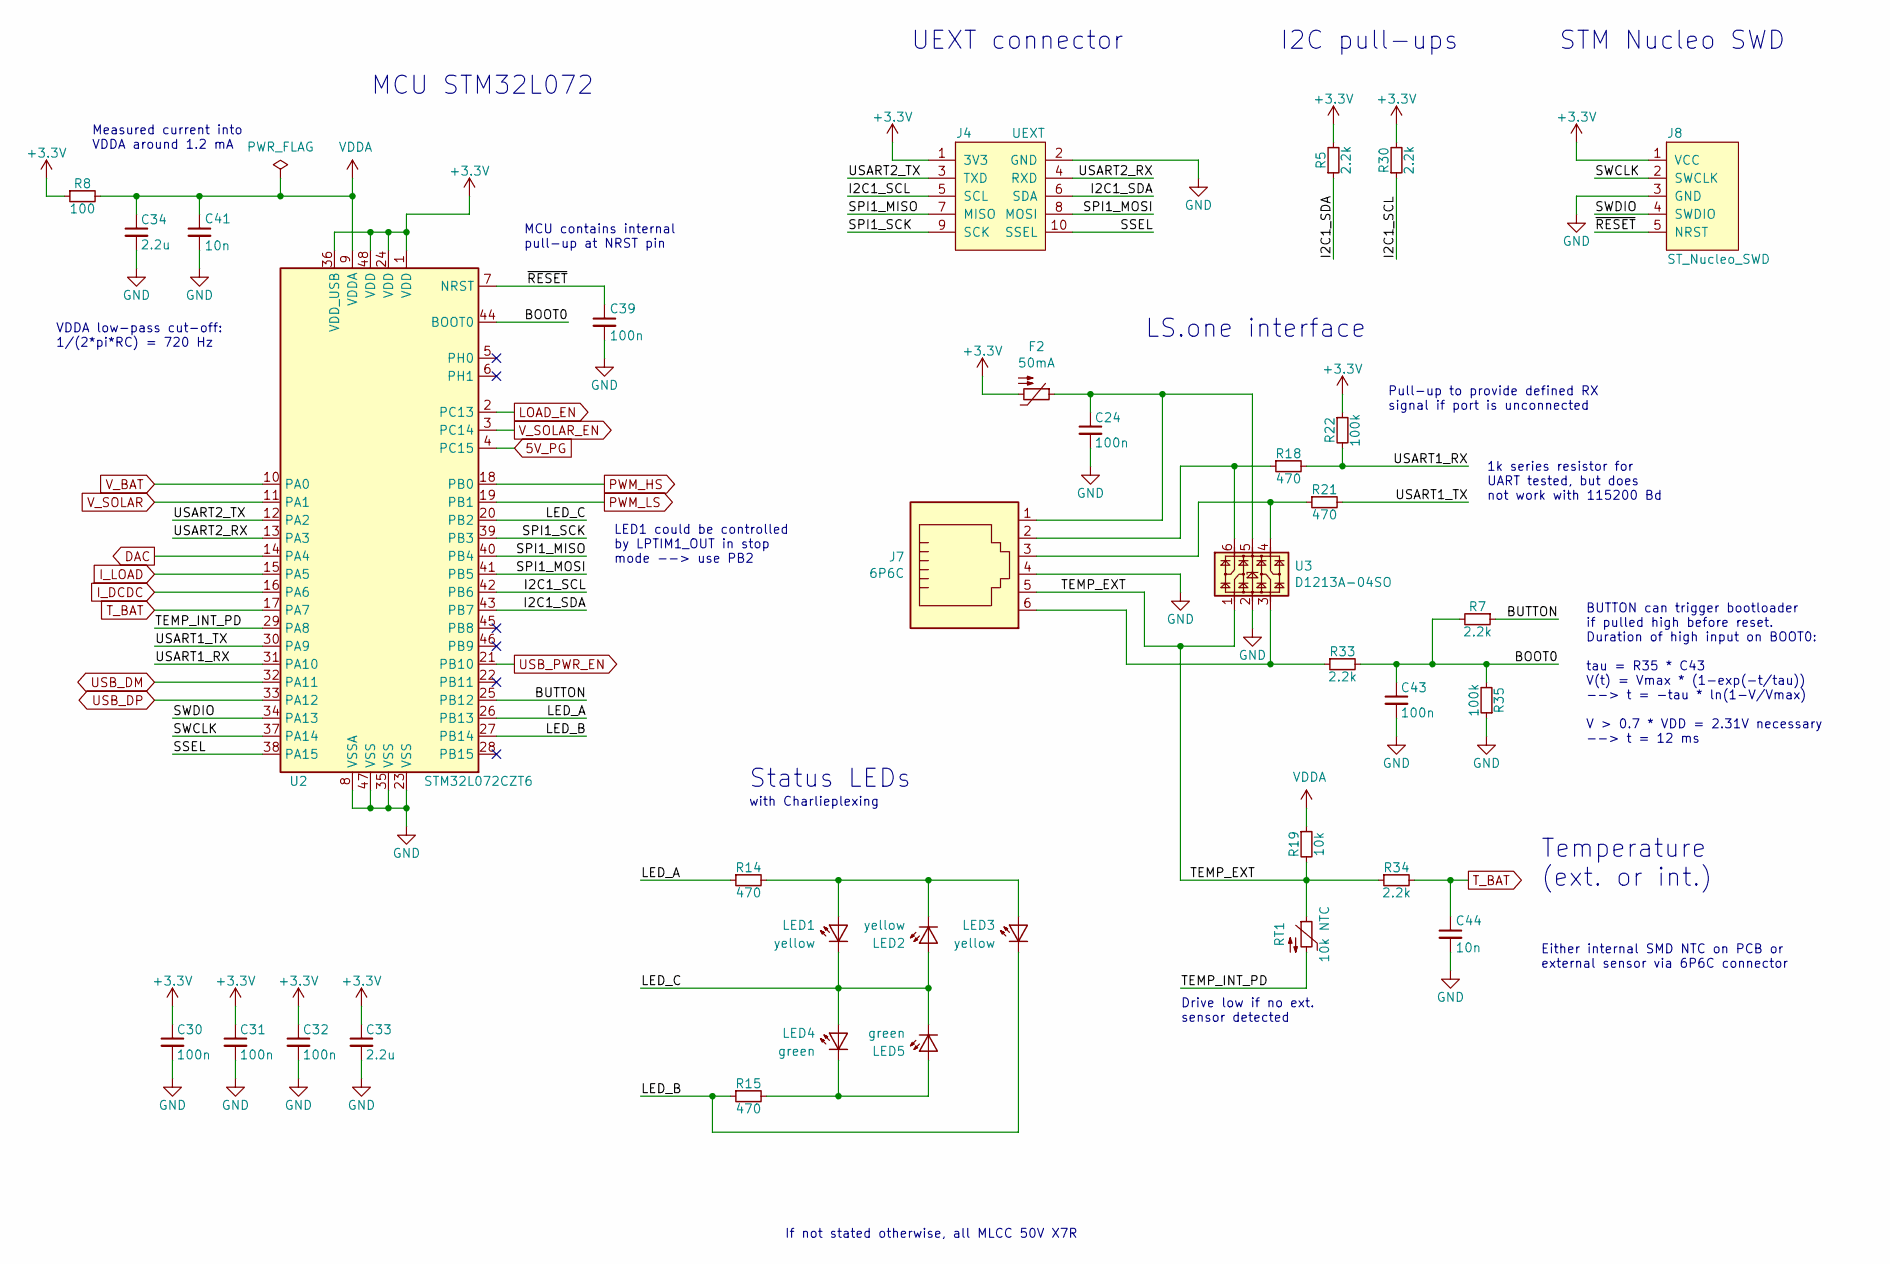
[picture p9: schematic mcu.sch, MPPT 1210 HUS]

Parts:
C24, C30, C31, C32, C39, C43: 100n; C_0603_1608; PartNumber CC0603KRX7R9BB104
C33, C34: 2.2u; C_0603_1608; PartNumber GRM188R61E225KA12D
C41, C44: 10n; C_0603_1608; PartNumber GCM188R72A103KA37D
F2: 50mA; R_1206_3216; PartNumber 0ZCJ0005FF2E
J4: UEXT; Box_Header_2x05x2.54mm_Straight; PartNumber 302-S101
J7: 6P6C; RJ25_6P6C_TabUp; PartNumber 615006138421
J8: ST_Nucleo_SWD; PinHeader_1x05_P2.54mm_Vertical; PartNumber M20-9990546
LED1, LED3: yellow; LED_0603_D3.0mm; PartNumber LTST-C191KSKT
LED2, LED5: green; LED_0603_D3.0mm; PartNumber LTST-C190KGKT
R5, R7, R30, R33, R34: 2.2k; R_0603_1608; PartNumber RC0603FR-072K2L
R8: 100; R_0603_1608; PartNumber RC0603FR-07100RL
R14, R15, R18, R21: 470; R_0603_1608; PartNumber RC0603FR-07470RL
R19: 10k; R_0603_1608; PartNumber RC0603FR-0710KL
R22, R35: 100k; R_0603_1608; PartNumber RC0603FR-07100KL
RT1: 10k NTC; R_0603_1608; PartNumber NCU18XH103E6SRB
U2: STM32L072CZT6; LQFP-48_7x7mm_P0.5mm; PartNumber STM32L072CZT6
U3: D1213A-04SO; SOT-23-6; PartNumber D1213A-04SO

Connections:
5V_PG: U2.4 (PC15); also elsewhere on the board
+3V3: C30.1, C31.1, C32.1, C33.1, F2.2, J4.1 (3V3), J8.1 (VCC), R5.2, R8.1, R22.1, R30.2, U2.1 (VDD), U2.24 (VDD), U2.36 (VDD_USB), U2.48 (VDD); also elsewhere on the board
/MCU/BOOT0: C43.1, R7.2, R33.2, R35.2, U2.44 (BOOT0)
/MCU/BUTTON: R7.1, U2.25 (PB12)
/MCU/I2C1_SCL: J4.5 (SCL), R30.1, U2.42 (PB6)
/MCU/I2C1_SDA: J4.6 (SDA), R5.1, U2.43 (PB7)
/MCU/LED_A: R14.1, U2.26 (PB13)
/MCU/LED_B: LED3.1 (K), R15.1, U2.27 (PB14)
/MCU/LED_C: LED1.1 (K), LED2.2 (A), LED5.1 (K), U2.20 (PB2); also elsewhere on the board
/MCU/SPI1_MISO: J4.7 (MISO), U2.40 (PB4)
/MCU/SPI1_MOSI: J4.8 (MOSI), U2.41 (PB5)
/MCU/SPI1_SCK: J4.9 (SCK), U2.39 (PB3)
/MCU/SSEL: J4.10 (SSEL), U2.38 (PA15)
/MCU/SWCLK: J8.2 (SWCLK), U2.37 (PA14)
/MCU/SWDIO: J8.4 (SWDIO), U2.34 (PA13)
/MCU/TEMP_EXT: J7.5, R19.2, R34.1, RT1.1, U3.1
/MCU/TEMP_INT_PD: RT1.2, U2.29 (PA8)
/MCU/USART1_RX: R18.2, R22.2, U2.31 (PA10)
/MCU/USART1_TX: R21.2, U2.30 (PA9)
/MCU/USART2_RX: J4.4 (RXD), U2.13 (PA3)
/MCU/USART2_TX: J4.3 (TXD), U2.12 (PA2)
/MCU/~RESET: C39.1, J8.5 (NRST), U2.7 (NRST)
DAC: U2.14 (PA4); also elsewhere on the board
GND: C24.2, C30.2, C31.2, C32.2, C33.2, C34.2, C39.2, C41.2, C43.2, C44.2, J4.2 (GND), J7.4, J8.3 (GND), R35.1, U2.8 (VSSA), U2.23 (VSS), U2.35 (VSS), U2.47 (VSS), U3.2; also elsewhere on the board
I_DCDC: U2.16 (PA6); also elsewhere on the board
I_LOAD: U2.15 (PA5); also elsewhere on the board
LOAD_EN: U2.2 (PC13); also elsewhere on the board
unnamed: C24.1, F2.1, J7.1, U3.5
unnamed: J7.2, R18.1, U3.6
unnamed: J7.3, R21.1, U3.4
unnamed: J7.6, R33.1, U3.3
PWM_HS: U2.18 (PB0); also elsewhere on the board
PWM_LS: U2.19 (PB1); also elsewhere on the board
T_BAT: C44.1, R34.2, U2.17 (PA7)
USB_DM: U2.32 (PA11); also elsewhere on the board
USB_DP: U2.33 (PA12); also elsewhere on the board
USB_PWR_EN: U2.21 (PB10); also elsewhere on the board
VDDA: C34.1, C41.1, R8.2, R19.1, U2.9 (VDDA)
V_BAT: U2.10 (PA0); also elsewhere on the board
V_SOLAR: U2.11 (PA1); also elsewhere on the board
V_SOLAR_EN: U2.3 (PC14); also elsewhere on the board

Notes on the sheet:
Status LEDs
MCU STM32L072
STM Nucleo SWD
If not stated otherwise, all MLCC 50V X7R
UEXT connector
I2C pull-ups
MCU contains internal pull-up at NRST pin
LED1 could be controlled by LPTIM1_OUT in stop mode --> use PB2
Measured current into VDDA around 1.2 mA
VDDA low-pass cut-off: 1/(2*pi*RC) = 720 Hz
with Charlieplexing
Temperature (ext. or int.)
Either internal SMD NTC on PCB or external sensor via 6P6C connector
LS.one interface
Drive low if no ext. sensor detected
1k series resistor for UART tested, but does not work with 115200 Bd
BUTTON can trigger bootloader if pulled high before reset. Duration of high input on BOOT0: tau = R35 * C43 V(t) = Vmax * (1-exp(-t/tau)) --> t = -tau * ln(1-V/Vmax) V > 0.7 * VDD = 2.31V necessary --> t = 12 ms
Pull-up to provide defined RX signal if port is unconnected

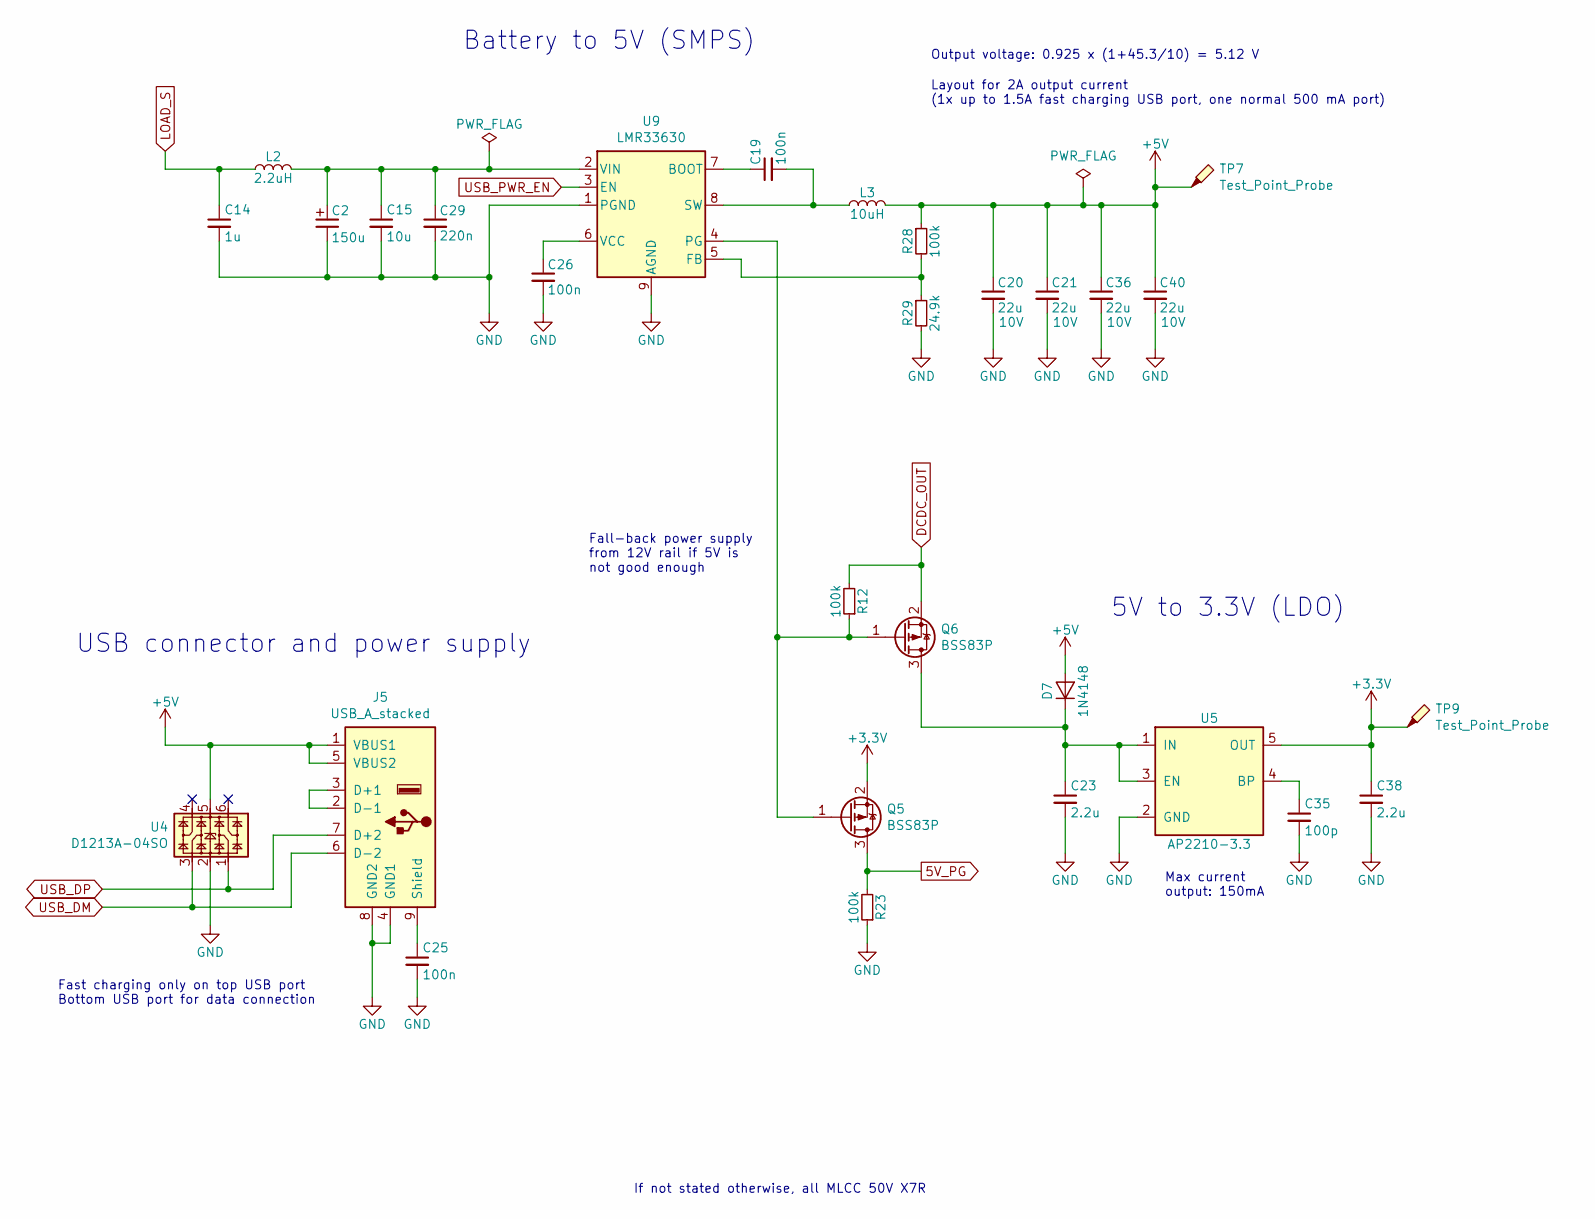
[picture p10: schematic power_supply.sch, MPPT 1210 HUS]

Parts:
C2: 150u; CP_Elec_8x6.2; PartNumber EEEFK1E151P
C14: 1u; C_0805_2012; PartNumber CC0805KKX7R9BB105
C15: 10u; C_1210_3225; PartNumber CL31A106KAHNNNE
C19, C25, C26: 100n; C_0603_1608; PartNumber CC0603KRX7R9BB104
C20, C21, C36, C40: 22u; C_1206_3216; PartNumber CL31B226MPHNNNE
C23, C38: 2.2u; C_0603_1608; PartNumber GRM188R61E225KA12D
C29: 220n; C_0603_1608; PartNumber GCM188R71E224KA55D
C35: 100p; C_0603_1608; PartNumber CC0603JRNPO9BN101
D7: 1N4148; D_SOD-123; PartNumber 1N4148W-7-F
J5: USB_A_stacked; USB_A_Wuerth_61400826021_Horizontal_Stacked; PartNumber UJ2-ADH-1-TH
L2: 2.2uH; L_1210_3225Metric; PartNumber BRL3225T2R2M
L3: 10uH; Bourns_SRN8040TA; PartNumber NR8040T100M
Q5, Q6: BSS83P; SOT-23; PartNumber BSS83P H6327
R12, R23, R28: 100k; R_0603_1608; PartNumber RC0603FR-07100KL
R29: 24.9k; R_0603_1608; PartNumber RC0603FR-0724K9L
TP7, TP9: Test_Point_Probe; TestPoint_Pad_D1.0mm
U4: D1213A-04SO; SOT-23-6; PartNumber D1213A-04SO
U5: AP2210-3.3; SOT-23-5; PartNumber AP2210K-3.3TRG1
U9: LMR33630; TI_SO-PowerPAD-8_ThermalVias; PartNumber LMR33630ADDA

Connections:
5V_PG: Q5.3 (D), R23.2; also elsewhere on the board
+3V3: C38.1, Q5.2 (S), TP9.1, U5.5 (OUT); also elsewhere on the board
+5V: C20.1, C21.1, C36.1, C40.1, D7.2 (A), J5.1 (VBUS1), J5.5 (VBUS2), L3.2, R28.1, TP7.1, U4.5
DCDC_OUT: Q6.2 (S), R12.2; also elsewhere on the board
GND: C2.2, C14.2, C15.2, C20.2, C21.2, C23.2, C25.2, C26.2, C29.2, C35.2, C36.2, C38.2, C40.2, J5.4 (GND1), J5.8 (GND2), R23.1, R29.2, U4.2, U5.2 (GND), U9.1 (PGND), U9.9 (AGND); also elsewhere on the board
LOAD_S: C14.1, L2.1; also elsewhere on the board
unnamed: C2.1, C15.1, C29.1, L2.2, U9.2 (VIN)
unnamed: C19.1, U9.7 (BOOT)
unnamed: C19.2, L3.1, U9.8 (SW)
unnamed: C23.1, D7.1 (K), Q6.3 (D), U5.1 (IN), U5.3 (EN)
unnamed: C25.1, J5.9 (Shield)
unnamed: C26.1, U9.6 (VCC)
unnamed: C35.1, U5.4 (BP)
unnamed: J5.2 (D-1), J5.3 (D+1)
unnamed: Q5.1 (G), Q6.1 (G), R12.1, U9.4 (PG)
unnamed: R28.2, R29.1, U9.5 (FB)
USB_DM: J5.6 (D-2), U4.3; also elsewhere on the board
USB_DP: J5.7 (D+2), U4.1; also elsewhere on the board
USB_PWR_EN: U9.3 (EN); also elsewhere on the board

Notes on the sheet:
Battery to 5V (SMPS)
5V to 3.3V (LDO)
If not stated otherwise, all MLCC 50V X7R
Output voltage: 0.925 x (1+45.3/10) = 5.12 V
USB connector and power supply
Layout for 2A output current (1x up to 1.5A fast charging USB port, one normal 500 mA port)
Fast charging only on top USB port Bottom USB port for data connection
Fall-back power supply from 12V rail if 5V is not good enough
Max current output: 150mA

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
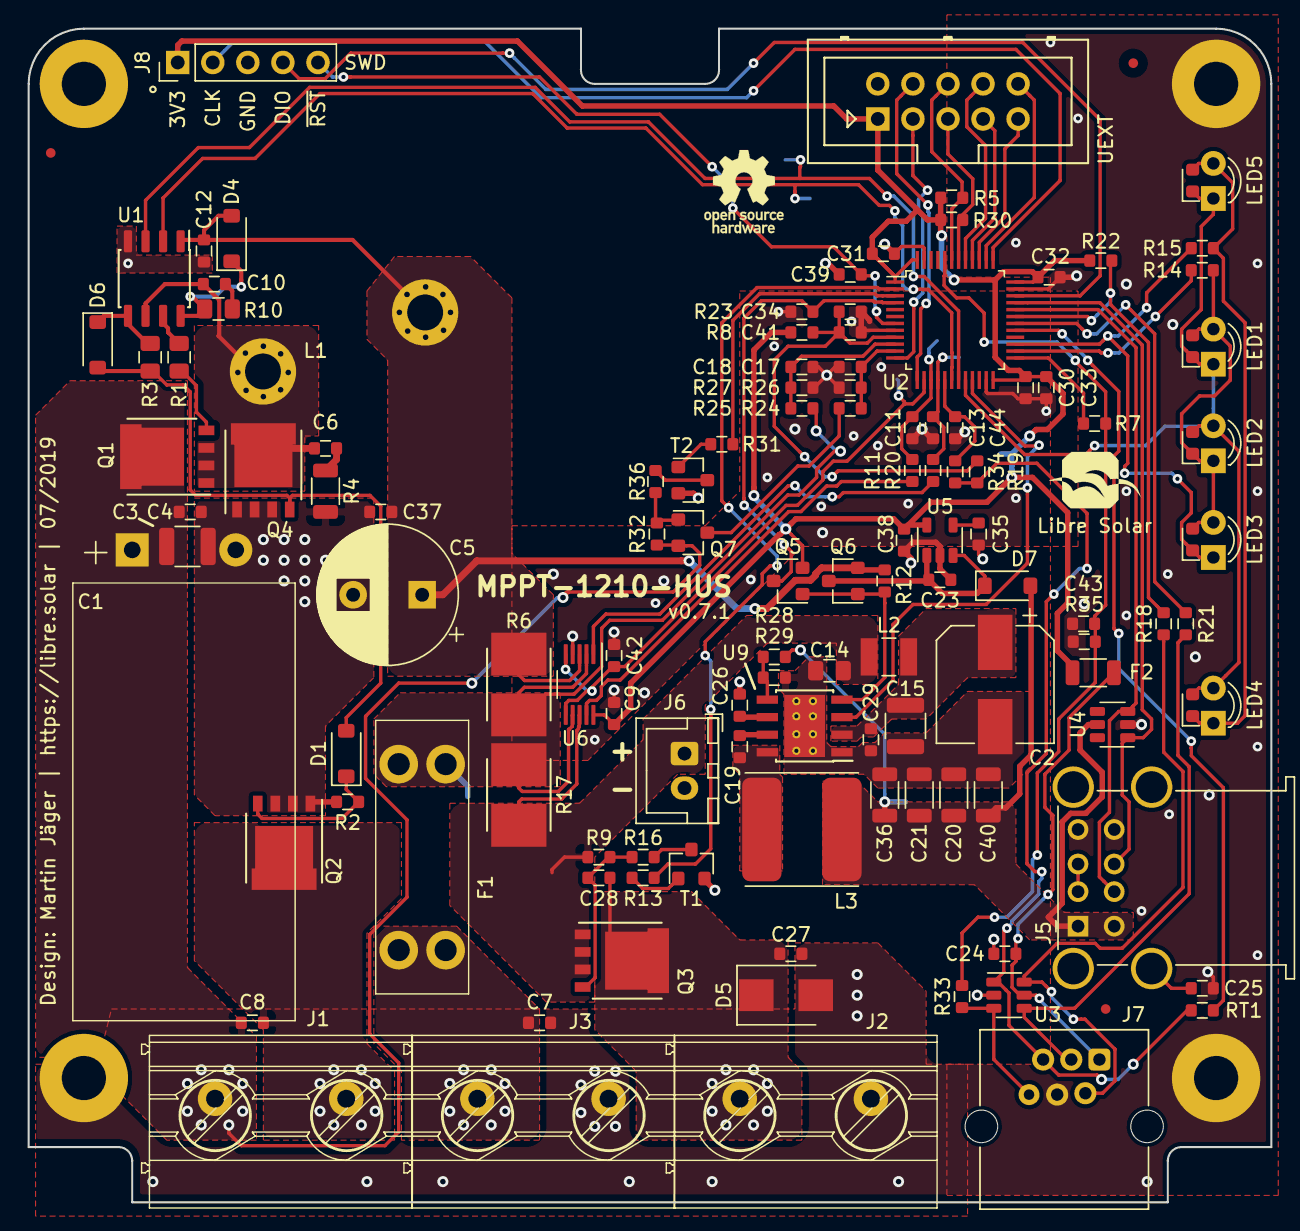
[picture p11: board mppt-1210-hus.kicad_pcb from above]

Board: 2 copper layers, 90.0 x 85.0 mm, 132 parts (0 on the bottom side), 79 nets.

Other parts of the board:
LED4: green; LED_0603_D3.0mm

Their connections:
/MCU/LED_C: LED4.2; also elsewhere on the board

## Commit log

2019-01-09 Initial commit (PCB revision 0.2)
    [analog_frontend.sch, dcdc.sch, mcu.sch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]
2019-01-09 PDF schematic added
2019-01-09 Several improvements (v0.4) after first tests
    - Ultra-low-power MCU STM32L072
    - Larger screw terminals
    - USB power supply replaced by more efficient SMPS
    - High-side load switch with P-MOS
    - High-side current measurement to include USB current in load measurement
    [analog_frontend.sch, dcdc.sch, mcu.sch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]
2019-04-02 Board shape adjusted and 6P6C connector added
    [analog_frontend.sch, dcdc.sch, mcu.sch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]
2019-04-16 Solar voltage input protection added
    [dcdc.sch, mcu.sch, mppt-10a.kicad_pcb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]
2019-06-29 Small changes and files renamed
    [dcdc.sch, mcu.sch, mppt-1210-hus.kicad_pcb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]
2019-07-01 GitHub linguist settings adjusted to recognize as KiCad
2019-07-25 Small adjustments after testing
    - MOSFET gate driver changed to reduce switch node ringing
    - Current measurement output filter time constant reduced to have less delay
    - BTN pin allows starting the bootloader if pulled to 3V3 before startup
    [dcdc.sch, mcu.sch, mppt-1210-hus.kicad_pcb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]
2020-04-20 Update specs and reduce max. input voltage
2020-04-20 Add automatically deployed interactive BOM
2021-05-02 Update documentation and license
    - Change license to CERN-OHL-W-2.0, which is more suitable for hardware
    - Add build folder including CSV and interactive BOM
    - Don't auto-generate interactive BOM anymore
    - Update schematic template and text fields
    - Use photo instead of rendered image
    - Rename branch master to main
    [dcdc.sch, mcu.sch, mppt-1210-hus.kicad_pcb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]

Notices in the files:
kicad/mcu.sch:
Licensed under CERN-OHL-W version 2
